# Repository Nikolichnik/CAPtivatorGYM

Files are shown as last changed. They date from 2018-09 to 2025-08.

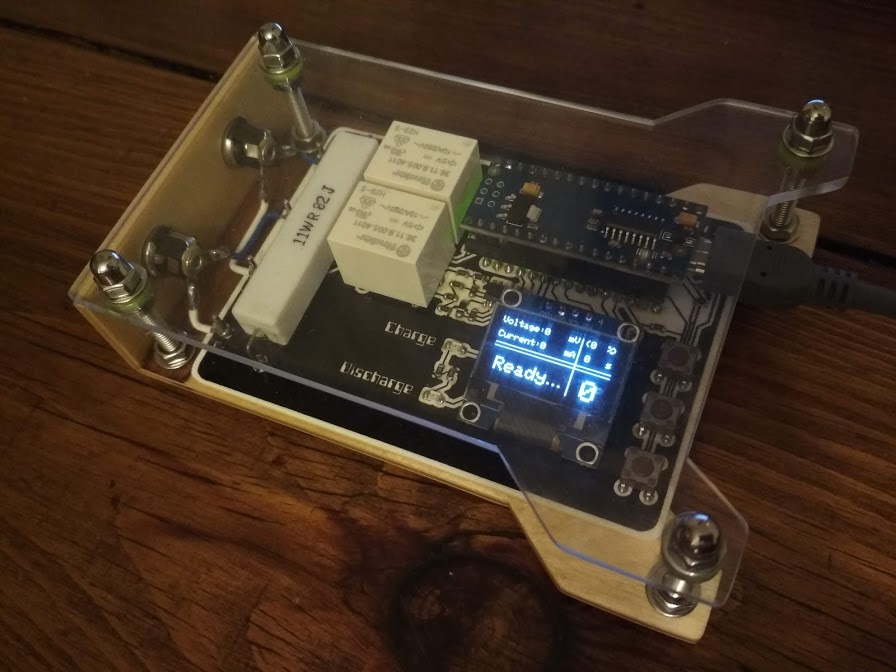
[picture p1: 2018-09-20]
CAPtivatorGYM.jpg

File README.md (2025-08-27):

# CAPtivatorGYM

<h4>Supercapacitor testing device.</h4> 

It is designed to automate process of charging/discharging supercapacitors while capturing, displaying and transmitting all relevant data both locally and through USB connection. Capable of independent operation as well as in conjuction with companion desktop software - <a href="https://github.com/Nikolichnik/CAPtivatorINTEL"><em>CAPtivatorINTEL</em></a>.

<hr>

<p align="center">
  
</p>

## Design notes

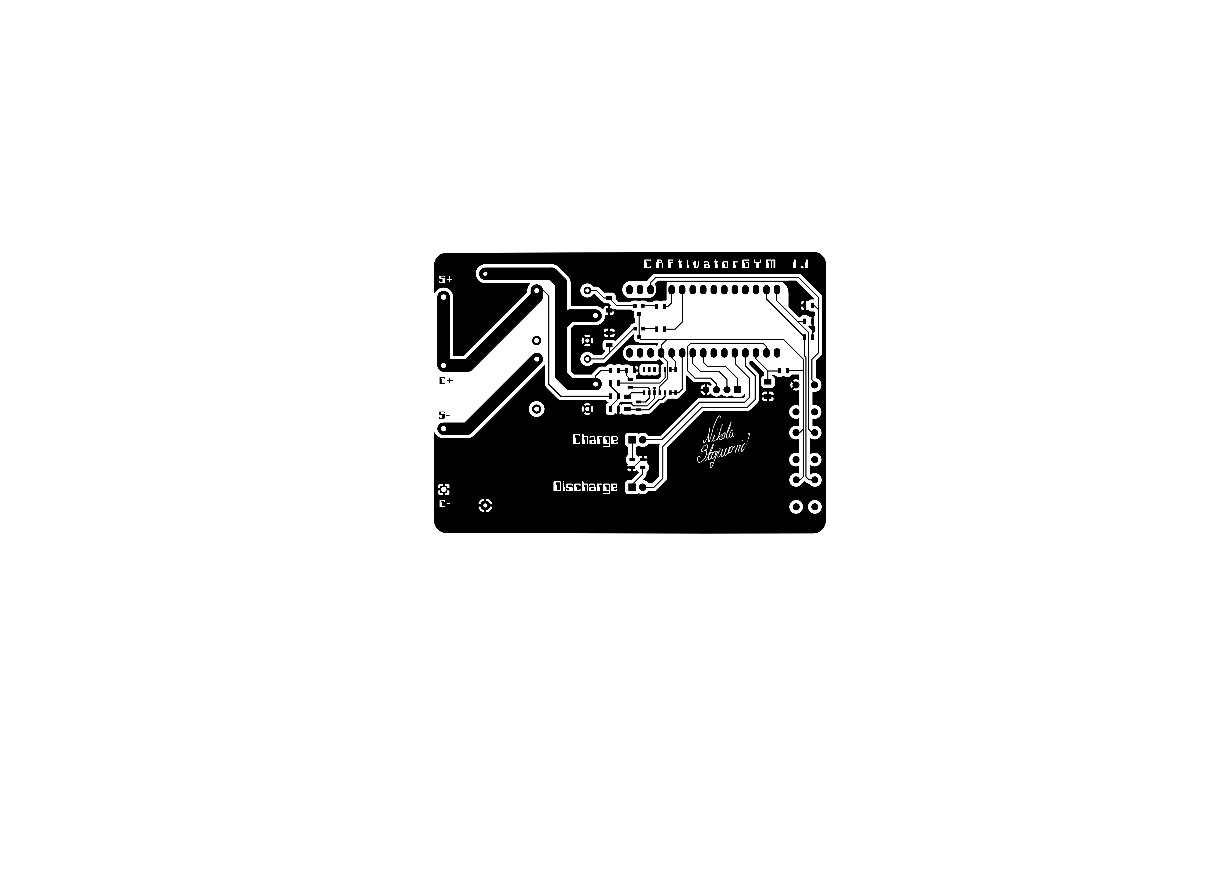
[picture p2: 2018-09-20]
pcb_KiCAD/CAP_gym-F.Cu.png

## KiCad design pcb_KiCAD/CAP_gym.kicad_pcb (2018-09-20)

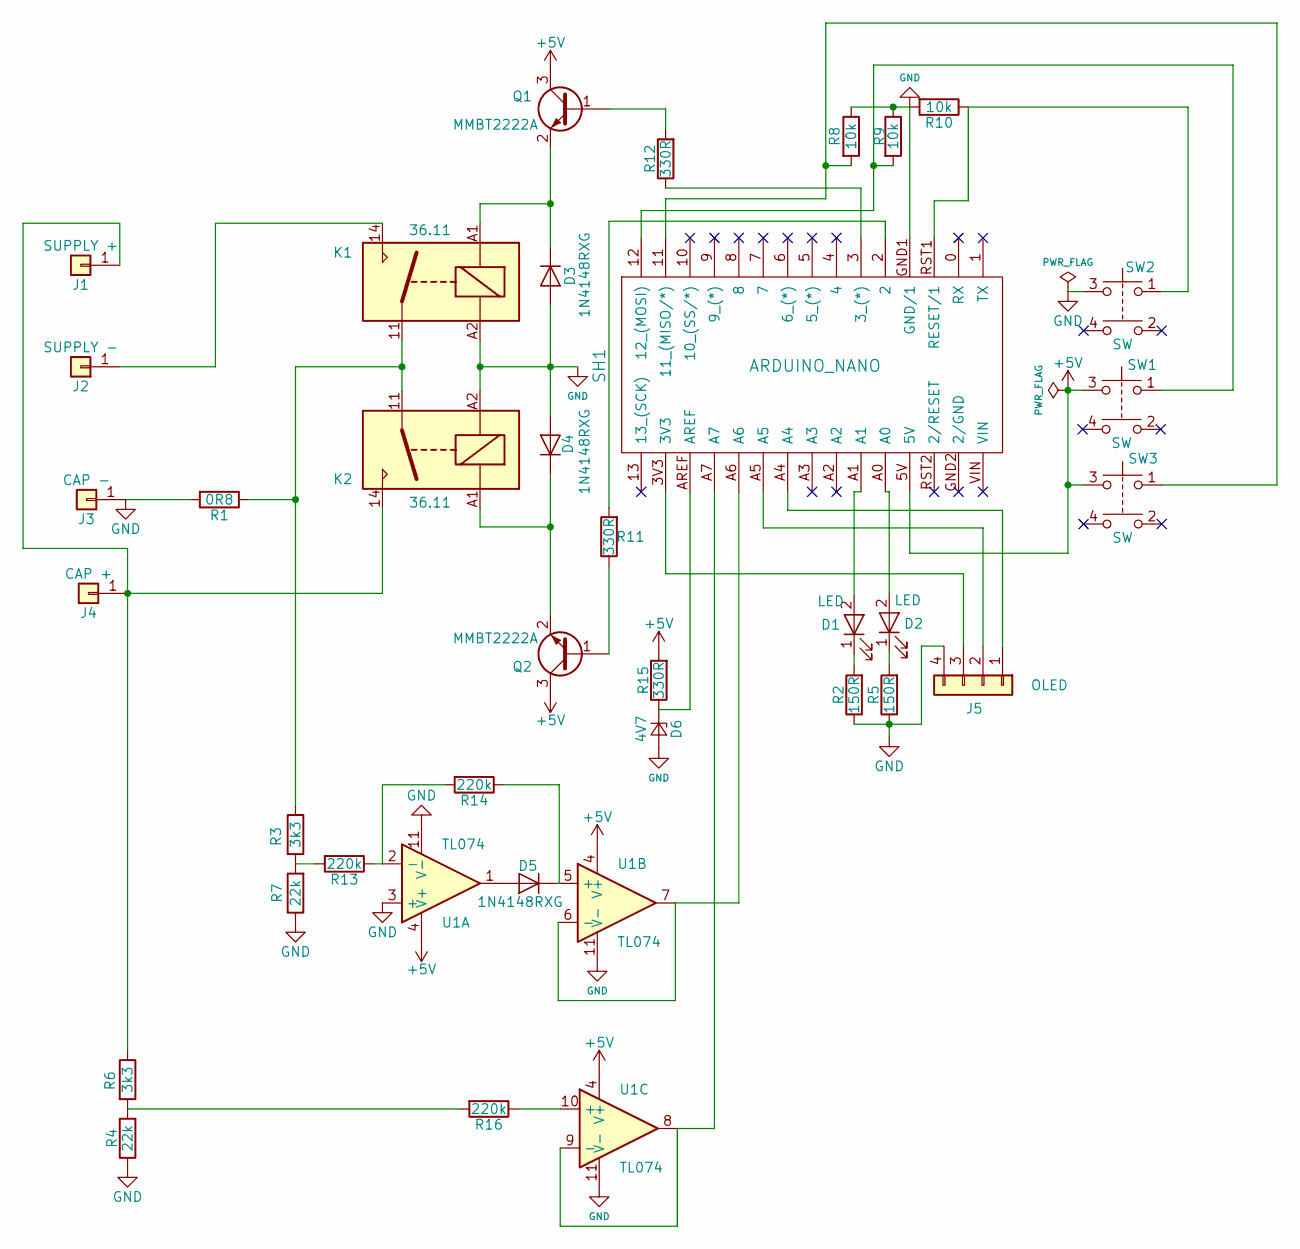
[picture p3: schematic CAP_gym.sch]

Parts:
D1, D2: LED; LED_D3.0mm
D3, D4, D5: 1N4148RXG; D_1206
D6: 4V7; D_MiniMELF
J1: SUPPLY +; Pin_Header_Straight_1x01_Pitch2.54mm
J2: SUPPLY -; Pin_Header_Straight_1x01_Pitch2.54mm
J3: CAP -; Pin_Header_Straight_1x01_Pitch2.54mm
J4: CAP +; Pin_Header_Straight_1x01_Pitch2.54mm
J5: OLED; Pin_Header_Straight_1x04_Pitch2.54mm
K1, K2: 36.11; Relay_SPDT_Finder_36.11
Q1, Q2: MMBT2222A; SOT-23
R1: 0R8; R_Axial_Power_L50.0mm_W9.0mm_P55.88mm
R2, R5: 150R; R_0805
R3, R6: 3k3; R_0805
R4, R7: 22k; R_0805
R8, R9, R10: 10k; R_0805
R11, R12, R15: 330R; R_0805
R13, R14, R16: 220k; R_0805
SH1: ARDUINO_NANO; ARDUINO_NANO_2_CONTOUR_ELL
SW1, SW2, SW3: SW; SW_TH_Tactile_Omron_B3F-10xx
U1: TL074; SO14

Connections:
+5V: Q1.3 (C), Q2.3 (C), R15.2, SH1.5V, SW1.3, SW3.3, U1.4 (V+)
GND: D3.2 (A), D4.2 (A), D6.2 (A), J3.1, J5.4, K1.A2, K2.A2, R1.2, R2.1, R4.1, R5.1, R7.1, R8.1, R9.1, R10.2, SH1.GND1 (GND/1), SW2.3, U1.3 (+), U1.11 (V-)
unnamed: D1.1 (K), R2.2
unnamed: D1.2 (A), SH1.A1
unnamed: D2.1 (K), R5.2
unnamed: D2.2 (A), SH1.A0
unnamed: D3.1 (K), K1.A1, Q1.2 (E)
unnamed: D4.1 (K), K2.A1, Q2.2 (E)
unnamed: D5.1 (K), R14.1, U1.5 (+)
unnamed: D5.2 (A), U1.1
unnamed: D6.1 (K), R15.1, SH1.AREF
unnamed: J1.1, J4.1, K2.14, R6.1
unnamed: J2.1, K1.14
unnamed: J5.1, SH1.A4
unnamed: J5.2, SH1.A5
unnamed: J5.3, SH1.3V3
unnamed: K1.11, K2.11, R1.1, R3.1
unnamed: Q1.1 (B), R12.2
unnamed: Q2.1 (B), R11.1
unnamed: R8.2, SH1.11 (11_(MISO/*)), SW3.1
unnamed: R9.2, SH1.12 (12_(MOSI)), SW1.1
unnamed: R10.1, SH1.RST1 (RESET/1), SW2.1
unnamed: R11.2, SH1.2
unnamed: R12.1, SH1.3 (3_(*))
unnamed: R13.1, R14.2, U1.2 (-)
unnamed: R3.2, R7.2, R13.2
unnamed: R16.1, U1.10 (+)
unnamed: R4.2, R6.2, R16.2
unnamed: SH1.A6, U1.6 (-), U1.7
unnamed: SH1.A7, U1.8, U1.9 (-)

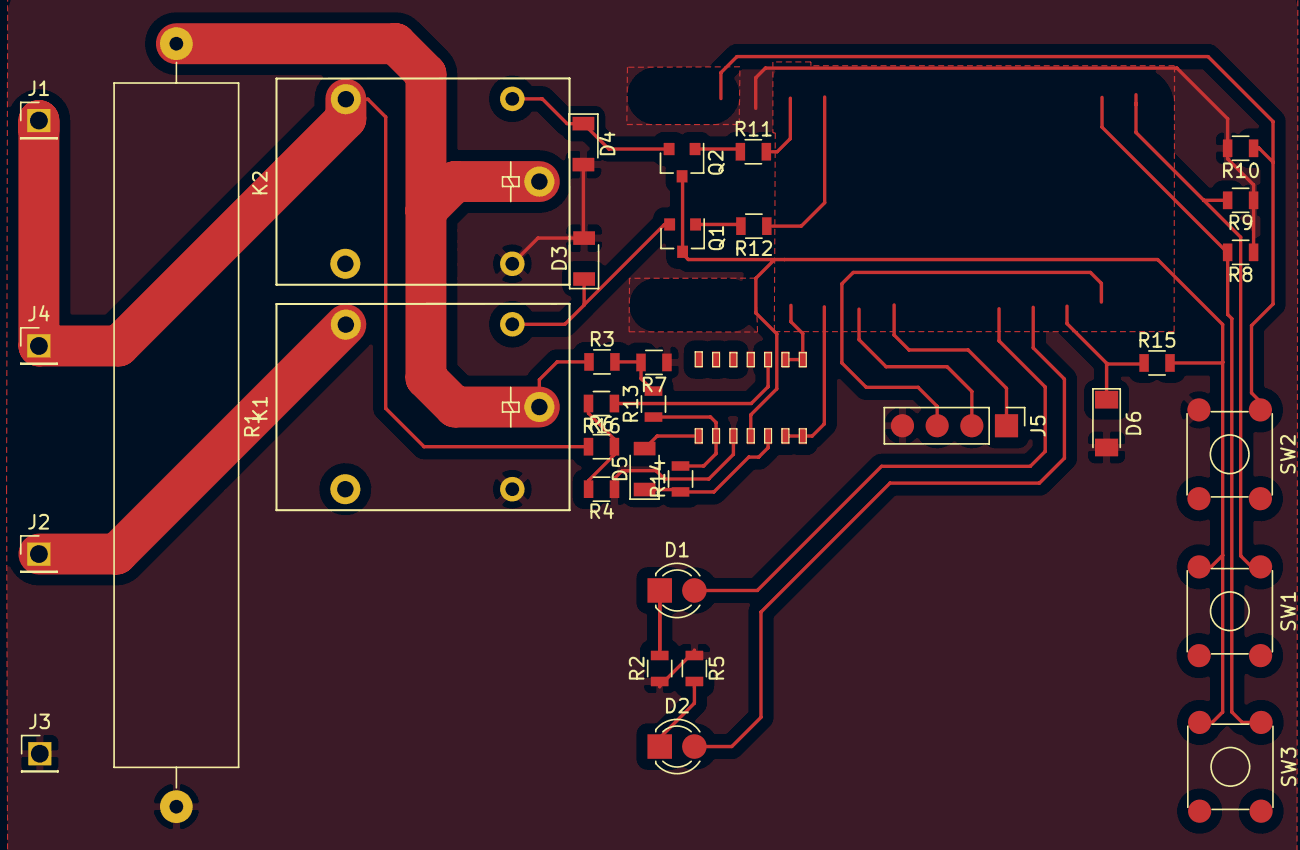
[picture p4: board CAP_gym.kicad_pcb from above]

Board: 2 copper layers, 36 parts (1 on the bottom side), 30 nets.

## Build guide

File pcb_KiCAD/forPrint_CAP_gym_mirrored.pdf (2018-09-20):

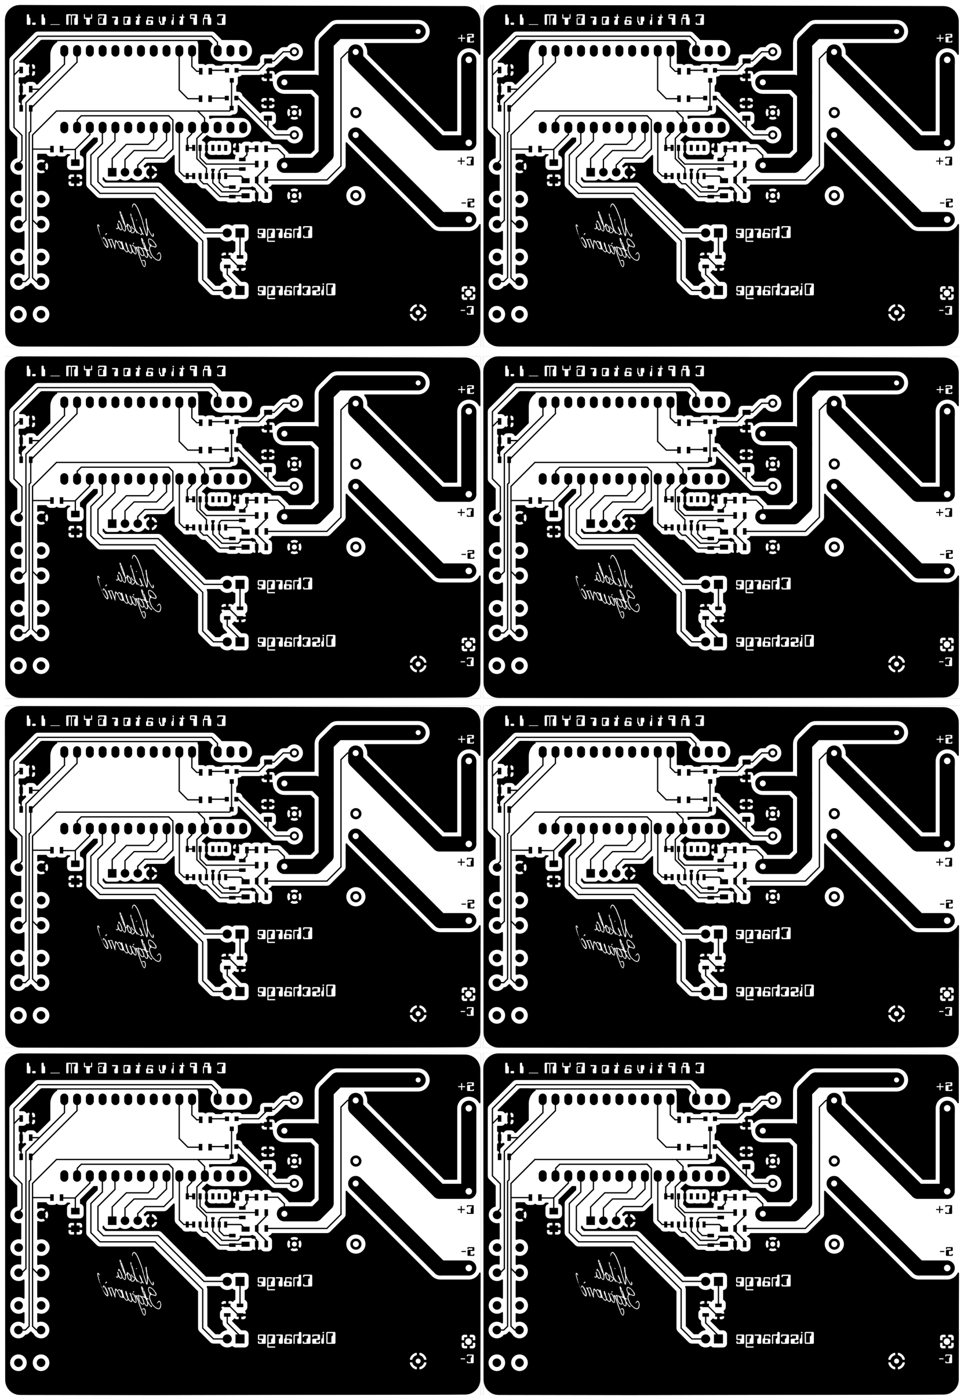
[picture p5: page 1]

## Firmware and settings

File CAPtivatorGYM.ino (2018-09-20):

#include <Wire.h>
#include <Adafruit_SSD1306.h>
#include <Adafruit_GFX.h>
#include "Pitches.h"

// bpSPD Button -----------------------------------------------------------------------------------
#define bpSPD 12

// OLED display TWI address -----------------------------------------------------------------------
#define OLED_ADDR   0x3C

// Reset pin not used on 4-pin OLED module --------------------------------------------------------
Adafruit_SSD1306 display(-1);  // -1 = no reset pin

// 128 x 32 pixel display -------------------------------------------------------------------------
#if (SSD1306_LCDHEIGHT != 64)
#error("Height incorrect, please fix Adafruit_SSD1306.h!");
#endif

// Voltage measurement ----------------------------------------------------------------------------
#define NUM_SAMPLES 10
#define REF_VOLTAGE 4.175

float R = 0.82;               // Initialisation of variables for resistance, and for maximum and
float Vmax = 2.70;            // minimum voltage
float Vmin = 0.10;
float I = 0.00;               // Initialisation of variable for current
float V = 0.00;               // Initialisation of variable for voltage on capacitors
float Vr = 0.00;              // Initialisation of variable for voltage on discharge resistor
float Vperc = 0;              // Declaration of variable percentage of Vmax
float C = 0;                  // Declaration of variable for capacitance
float t = 0;                  // Initialisation of variable for time

byte cycle = 0;               // Initialise counter for current cycle, number of cycles
byte cycles = 3;
byte cyclesMax = 9;           // Initialisation of variable determining maximum number of cycles

// Relays ---------------------------------------------------------------------------------------
byte relayCS = 3;              // Define pin connected to charging relay (CS == "Capacitor - Supply")
byte relayCD = 2;              // Define pin connected to discharging relay (CD == "Capacitor - Discharge")
// Button bpT -----------------------------------------------------------------------------------
int bpTPin = 11;              // The number of the input pin for screen toggle
boolean bpTState = HIGH;      // The current state of the output pin
int bpTReading;               // The current reading from the input pin
boolean bpTPrevious = LOW;    // The previous reading from the input pin
long bpTTime = 0;             // The last time the output pin was toggled
long bpTDebounce = 100;       // The debounce time, increase if the output flickers
int bpTVar = 0;               // Variable recording state of screen Toggle button
// Button bpSPD ---------------------------------------------------------------------------------
int bpSPDVar = 1;             // Variable recording state of screen bpSPD button
// Button timing variables
int debounce = 20;            // ms debounce period to prevent flickering when pressing or releasing the button
int DCgap = 250;              // max ms between clicks for a double click event
int holdTime = 1000;          // ms hold period: how long to wait for press+hold event
int longHoldTime = 3000;      // ms long hold period: how long to wait for press+hold event
// Other button variables
boolean buttonVal = HIGH;     // value read from button
boolean buttonLast = HIGH;    // buffered value of the button's previous state
boolean DCwaiting = false;    // whether we're waiting for a double click (down)
boolean DConUp = false;       // whether to register a double click on next release, or whether to wait and click
boolean singleOK = true;      // whether it's OK to do a single click
long downTime = -1;           // time the button was pressed down
long upTime = -1;             // time the button was released
boolean ignoreUp = false;     // whether to ignore the button release because the click+hold was triggered
boolean waitForUp = false;          // when held, whether to wait for the up event
boolean holdEventPast = false;      // whether or not the hold event happened already
boolean longHoldEventPast = false;  // whether or not the long hold event happened already
// Caps -----------------------------------------------------------------------------------------
byte capVoltage = A7;
byte capCurrent = A6;
// LEDs -----------------------------------------------------------------------------------------
byte LEDCharge = A1;
byte LEDDischarge = A0;
// Graph vars -------------------------------------------------------------------------------------
double x, y;
double ox, oy ;
// Koef -------------------------------------------------------------------------------------------
double koef = 1.1376;
// Speaker ----------------------------------------------------------------------------------------
byte speaker = 10;

//-------------------------------------------------------------------------------------------------
//                                          SETUP/LOOP
//-------------------------------------------------------------------------------------------------


void setup() {
  analogReference(EXTERNAL);
  Serial.begin(9600);
  display.begin(SSD1306_SWITCHCAPVCC, OLED_ADDR);
  display.display();
  delay(2000);
  display.clearDisplay();  
  
  // Relays ------------------------------------------------------------------------------------
  pinMode(relayCS, OUTPUT);
  digitalWrite(relayCS, LOW);
  pinMode(relayCD, OUTPUT);
  digitalWrite(relayCD, LOW);
  // Button bpT---------------------------------------------------------------------------------
  pinMode(bpTPin, INPUT);
  // Button bpSPD-------------------------------------------------------------------------------
  pinMode(bpSPD, INPUT);
  // LEDs---------------------------------------------------------------------------------------
  pinMode(LEDCharge, OUTPUT);
  digitalWrite(LEDCharge, LOW);
  pinMode(LEDDischarge, OUTPUT);
  digitalWrite(LEDDischarge, LOW);

  testdrawline();
  display.display();
  display.clearDisplay();

  playMelody(1);
}

void loop() {
  
  checkSPD();
  
  switch (bpSPDVar) {
    case 1:
      cycle = 0;
      idle();      
      break;
    case 2:
      advanceCyclesNumber();
      break;
    case 3:    
    if (cycle < cycles) {
        cycle++;
        discharge();
        charge();
      } else {
        discharge();
        playMelody(3);
        bpSPDVar = 1;
        cycle = 0;
        Serial.println("Measurement complete!");     
      }
      break;
  }
}

//-------------------------------------------------------------------------------------------------
//                                        FUNCTIONS
//-------------------------------------------------------------------------------------------------

void discharge() {                      // Function for discharging   
  unsigned long startTime = millis();         // Start measuring time in milliseconds
  unsigned long currentTime = 0;              // Mark down time in milliseconds again
  unsigned long tPause = 0;
  Serial.println("Discharging...");  
  V = measureVoltage();
  display.clearDisplay();                      // Calculate percentage that current voltage is to value Vmax
  while (V > Vmin) {                           // While measured voltage is lower than Vmax...
    checkSPD();                                // Check state of SPD button
      currentTime = millis();
      if (bpSPDVar == 1) {
        digitalWrite(relayCD, LOW);            // Disconnect capacitors discharging resistor
        digitalWrite(relayCS, LOW);            // Connect capacitors to supply
        digitalWrite(LEDDischarge, LOW);
        tPause = t - (currentTime - startTime);
      } else if (bpSPDVar == 2) { 
        advanceCyclesNumber();
      } else if (bpSPDVar == 4) {
        bpSPDVar = 1; 
        break;
      } else {
        digitalWrite(LEDDischarge, HIGH);       // Turn on charge LED
        digitalWrite(relayCS, LOW);             // Disconnect capacitors discharging resistor
        digitalWrite(relayCD, HIGH);            // Connect capacitors to supply
        V = measureVoltage();
        Vperc = (V / Vmax) * 100;
        I = measureCurrent();                   // Read voltage on discharge resistor, taking voltage divider into consideration
                                                // Calculate capacitor discharge current (converted to mA)        
        t = currentTime - startTime + tPause;   // Calculate time passed between two marks
        if (V > ((0.368 * Vmax)+0.002)) {       // While voltage is less than 63.2% of Vmin,
          C = -1;                               // set C to -1 (see displayOut())
        } else if (V > ((0.368 * Vmax)-0.002) && V < ((0.368 * Vmax)+0.002)) {         // When voltage reaches 63.2% of Vmax,
          C = (t / 1000) / R;                   // calculate capacitance (while converting time from ms to s)
        }
        displayOut();                           // Keep updating display
        Serial.print((int)(V * 1000));          // Send values for V (converted to mV), I (in mA), C (in F) and t (converted to s) over Serial
        Serial.print(",");
        Serial.print((int)I);
        Serial.print(",");        
        Serial.println((int)(t / 1000));
        delay(3);
      }
  }  
  digitalWrite(relayCD, LOW);                   // Disconnect capacitors from supply
  digitalWrite(LEDDischarge, LOW);              // Turn off charge LED
  t = 0;                                        // Reset time to 0
  Serial.print("Discharge cycle ");
  Serial.print(cycle);
  Serial.print(" done! C = ");
  Serial.println(C);
  playMelody(2);
  //delay(3000); 
}

void charge() {                         // Function for charging  
  unsigned long startTime = millis();         // Start measuring time in milliseconds
  unsigned long currentTime = 0;              // Mark down time in milliseconds again
  unsigned long tPause = 0;
  Serial.println("Charging...");
  V = measureVoltage();
  display.clearDisplay();                     // Calculate percentage that current voltage is to value Vmax
  while (V < Vmax) {                          // While measured voltage is lower than Vmax...
    checkSPD();                               // Check state of SPD button
      currentTime = millis();
      if (bpSPDVar == 1) {
        digitalWrite(relayCD, LOW);           // Disconnect capacitors discharging resistor
        digitalWrite(relayCS, LOW);           // Connect capacitors to supply
        digitalWrite(LEDCharge, LOW);
        tPause = t - (currentTime - startTime);
      } else if (bpSPDVar == 2) { 
        advanceCyclesNumber();
      } else if (bpSPDVar == 4) {
        bpSPDVar = 1; 
        break;
      } else {
        digitalWrite(LEDCharge, HIGH);          // Turn on charge LED
        digitalWrite(relayCD, LOW);             // Disconnect capacitors discharging resistor
        digitalWrite(relayCS, HIGH);            // Connect capacitors to supply
        V = measureVoltage();
        Vperc = (V / Vmax) * 100;
        I = measureCurrent();                   // Read voltage on discharge resistor, taking voltage divider into consideration
                                                // Calculate capacitor discharge current (converted to mA)        
        t = currentTime - startTime + tPause;   // Calculate time passed between two marks
        if (V < ((0.632 * Vmax)-0.002)) {       // While voltage is less than 63.2% of Vmin,
          C = -1;                               // set C to -1 (see displayOut())
        } else if (V > ((0.632 * Vmax)-0.002) && V < ((0.632 * Vmax)+0.002)) {         // When voltage reaches 63.2% of Vmax,
          C = (t / 1000) / R;                   // calculate capacitance (while converting time from ms to s)
        }
        displayOut();                           // Keep updating display
        Serial.print((int)(V * 1000));          // Send values for V (converted to mV), I (in mA), C (in F) and t (converted to s) over Serial
        Serial.print(",");
        Serial.print((int)I);
        Serial.print(",");        
        Serial.println((int)(t / 1000));
        delay(3);
      }
  }  
  digitalWrite(relayCS, LOW);         // Disconnect capacitors from supply
  digitalWrite(LEDCharge, LOW);       // Turn off charge LED
  t = 0;                              // Reset time to 0
  Serial.print("Charge cycle ");
  Serial.print(cycle);
  Serial.print(" done! C = ");
  Serial.println(C);
  playMelody(2);
  //delay(3000);
}

void idle() {                           // Function for idling
  digitalWrite(relayCS, LOW);           // Disconnect capacitors from supply
  digitalWrite(relayCD, LOW);           // Disconnect capacitors from discharge resistor
  //Serial.println("Ready...");
  V = measureVoltage();
  Vperc = (V / Vmax) * 100;             // Calculate percentage that current voltage is to value Vmax
  I = measureCurrent();
  displayOut();
}

void displayOut() {                       // Function for display handling
  bpTCheck();                             // This way user can switch between readout and graph mid-measurement. Graph would be partial, however.
  if (bpTVar == 0) {
    display.clearDisplay();
    display.setTextColor(WHITE);
    display.setTextSize(1);
    display.setCursor(0, 0);
    display.print("Voltage: ");
    display.setCursor(48, 0);
    display.print((int)(V * 1000));            // Voltage converted to mV
    display.setCursor(75, 0);
    display.print("mV");
    display.setCursor(93, 0);
    display.print("(");
    display.setCursor(99, 0);
    display.print((int)Vperc);
    display.setCursor(117, 0);
    display.print("%");
    display.setCursor(121, 0);
    display.print(")");
    display.setCursor(0, 16);
    display.print("Current: ");
    display.setCursor(48, 16);
    display.print((int)I);
    display.setCursor(75, 16);
    display.print("mA");
    display.setCursor(97, 16);
    display.print((int)(t / 1000));            // Time converted from ms to s
    display.setCursor(120, 16);
    display.print("s");
    display.drawFastHLine(0, 29, 128, WHITE);
    display.drawFastHLine(0, 33, 128, WHITE);
    display.drawFastVLine(89, 0, 64, WHITE);
    display.setCursor(6, 45);
    if (bpSPDVar == 1) {
      display.setTextSize(2);
      display.print("Ready");
      display.setCursor(65, 51);
      display.setTextSize(1);
      display.print("...");
    } else if (bpSPDVar == 2) {
      display.setCursor(4, 45);
      display.setTextSize(2);
      display.print("#CyS:");
      display.setTextSize(3);
      display.setCursor(65, 42);
      display.print(cycles);
    } else {
      display.setTextSize(3);
      if (C == -1) {
        display.setCursor(6, 35);
        display.print("...");
      } else {
        display.setCursor(6, 42);
        display.print((int)C);
      }
      display.setCursor(69, 42);
      display.print("F");
    }
    display.setTextSize(3);
    display.setCursor(103, 42);
    display.print(cycle);
    display.display();
    display.clearDisplay();
  } else {
    DrawCGraph(display, t / 1000, V, 9, 60, 100, 57, 0, 1500, 50, 0, 3, 1, 0, "", true);
    DrawBarChartV(display, I / 1000, 113,  61, 5, 57, 0, 3 , 1, 0, "", true);
  }
}

void DrawCGraph(Adafruit_SSD1306 &d, double x, double y, double gx, double gy, double w, double h, double xlo, double xhi, double xinc, double ylo, double yhi, double yinc, double dig, String title, boolean Redraw) {

  /*

    function to draw a cartesian coordinate system and plot whatever data you want
    just pass x and y and the graph will be drawn huge arguement list

    &display to pass the display object, mainly used if multiple displays are connected to the MCU
    x = x data point
    y = y datapont
    gx = x graph location (lower left)
    gy = y graph location (lower left)
    w = width of graph
    h = height of graph
    xlo = lower bound of x axis
    xhi = upper bound of x asis
    xinc = division of x axis (distance not count)
    ylo = lower bound of y axis
    yhi = upper bound of y asis
    yinc = division of y axis (distance not count)
    title = title of graph
    &redraw = flag to redraw graph on fist call only

  */

  double i;
  double temp;
  int rot, newrot;

  if (Redraw == true) {
    /*Redraw = false;
      d.fillRect(0, 0,  127 , 16, WHITE);
      d.setTextColor(BLACK, WHITE);
      d.setTextSize(1);
      d.setCursor(2, 4);
      d.println(title);*/
    ox = (x - xlo) * ( w) / (xhi - xlo) + gx;
    oy = (y - ylo) * (gy - h - gy) / (yhi - ylo) + gy;
    // draw y scale
    d.setTextSize(1);
    d.setTextColor(WHITE, BLACK);
    for ( i = ylo; i <= yhi; i += yinc) {
      // compute the transform
      // note my transform funcition is the same as the map function, except the map uses long and we need doubles
      temp =  (i - ylo) * (gy - h - gy) / (yhi - ylo) + gy;
      if (i == 0) {
        d.drawFastHLine(gx - 2, temp, w + 2, WHITE);
      }
      else {
        d.drawFastHLine(gx - 2, temp, 2, WHITE);
      }
      d.setCursor(gx - 9, temp - 3);
      d.println(i, dig);
    }
    // draw x scale
    for (i = xlo; i <= xhi; i += xinc) {
      // compute the transform
      d.setTextSize(1);
      d.setTextColor(WHITE, BLACK);
      temp =  (i - xlo) * ( w) / (xhi - xlo) + gx;
      if (i == 0) {
        d.drawFastVLine(temp, gy - h, h + 2, WHITE);
      }
      else {
        d.drawFastVLine(temp, gy, 2, WHITE);
      }
      d.setCursor(temp, gy + 6);
      d.println(i, dig);
    }
  }

  // graph drawn now plot the data
  // the entire plotting code are these few lines...

  x =  (x - xlo) * ( w) / (xhi - xlo) + gx;
  y =  (y - ylo) * (gy - h - gy) / (yhi - ylo) + gy;
  d.drawLine(ox, oy, x, y, WHITE);
  d.drawLine(ox, oy - 1, x, y - 1, WHITE);
  ox = x;
  oy = y;

  // up until now print sends data to a video buffer NOT the screen
  // this call sends the data to the screen
  d.display();
}

void DrawBarChartV(Adafruit_SSD1306 &d, double curval, double x , double y , double w, double h , double loval , double hival , double inc , double dig, String label, bool Redraw) {

  /*
    This method will draw a vertical bar graph for single input
    it has a rather large arguement list and is as follows

    &d to pass the display object, mainly used if multiple displays are connected to the MCU
    curval = date to graph (must be between loval and hival)
    x = position of bar graph (lower left of bar)
    y = position of bar (lower left of bar)
    w = width of bar graph
    h =  height of bar graph (does not need to be the same as the max scale)
    loval = lower value of the scale (can be negative)
    hival = upper value of the scale
    inc = scale division between loval and hival
    dig = format control to set number of digits to display. (not includeing the decimal)
    label = bottom lable text for the graph
    redraw = flag to redraw display. only on first pass (to reduce flickering)

  */

  double stepval, my, level, i, data;

  if (Redraw) {
    /*Redraw = false;
      d.fillRect(0, 0,  127 , 14, WHITE);
      d.setTextColor(BLACK, WHITE);
      d.setTextSize(1);
      d.setCursor(2, 4);
      d.println(label);*/
    // step val basically scales the hival and low val to the height
    // deducting a small value to eliminate round off errors
    // this val may need to be adjusted
    stepval = ( inc) * (double (h) / (double (hival - loval))) - .001;
    for (i = 0; i <= h; i += stepval) {
      my =  y - h + i;
      d.drawFastHLine(x + w + 0, my, 2, WHITE);
      // draw lables
      d.setTextSize(1);
      d.setTextColor(WHITE, BLACK);
      d.setCursor(x + w + 4, my - 3 );
      data = hival - ( i * (inc / stepval));
      d.print(data, dig);
    }
  }
  // compute level of bar graph that is scaled to the  height and the hi and low vals
  // this is needed to accompdate for +/- range
  level = (h * (((curval - loval) / (hival - loval))));
  // draw the bar graph
  // write a upper and lower bar to minimize flicker cause by blanking out bar and redraw on update
  d.drawRect(x, y - h, w, h, WHITE);
  d.fillRect(x, y - h, w, h - level,  BLACK);
  d.drawRect(x, y - h, w, h, WHITE);
  d.fillRect(x, y - level, w,  level, WHITE);
  // up until now print sends data to a video buffer NOT the screen
  // this call sends the data to the screen
  d.display();
}

void advanceCyclesNumber() {            // Function for advancing number of cycles
  if (cycles < cyclesMax) {
    cycles++;
  } else {
    cycles = 1;
  }
  Serial.println(cycles);
  displayOut();
  delay(1000);
  bpSPDVar = 1;
}

boolean bpTCheck() {                    // Function for checking state of toggle button
  bpTReading = digitalRead(bpTPin);
  if (bpTReading == HIGH && bpTPrevious == LOW && millis() - bpTTime > bpTDebounce) {
    if (bpTState == HIGH) {
      bpTState = LOW;
      bpTVar = 0;
    } else {
      bpTState = HIGH;
      bpTTime = millis();
      bpTVar = 1;
    }
  }
  bpTPrevious = bpTReading;
  return bpTState;
}

void testdrawline() {
  display.clearDisplay();
  for (int16_t i = 0; i < display.height(); i += 4) {
    display.drawLine(display.width() - 1, 0, 0, i, WHITE);
    display.display();
    delay(1);
  }
  for (int16_t i = 0; i < display.width(); i += 4) {
    display.drawLine(display.width() - 1, 0, i, display.height() - 1, WHITE);
    display.display();
    delay(1);
  }
}
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

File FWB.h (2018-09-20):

// for types of button presses for the Arduino: click, double-click, long press (and release), very long press 
// might work with other controllers. modified from: http://pastebin.com/gQLTrHVF
/*
  i had to make a few changes (update it?) to make the code work. main changes:
  1. REMOVED: #include "WProgram.h" (no longer required).
  2. CHANGED: bpUP TO bp.
  3. ADDED: event listeners for ALL four types of presses in the sample code.
  4. CHANGED: time intervals for single, double, long clicks and for long press. these feel more intuitive to me.
  5. CHANGED: event OnLongPress is raised ONLY after the button is released. this, again, feels more intuitive. code is tested and at http://pastebin.com/87cCn6h9
*/

//
// jb_exe
// Class from the code of JEFF'S ARDUINO BLOG
// http://jmsarduino.blogspot.com/2009/10/4-way-button-click-double-click-hold.html
// 
// the modified version at http://pastebin.com/gQLTrHVF
// further modified by mahesh [at] tinymogul.com
//
// Further edited by Nikolichnik (nikola7sto@gmail.com)
//

// How to use me :
// "FWB_Project.pde"
// #include "FWB.h"
// #define BP 0 //the pin where your button is connected
//
// FWB bp;
//
// void OnClick(int pin) {
//   //Your code here
// }
//
// void OnDblClick(int pin) {
//   //Your code here
// }
//
// void OnLongPress(int pin) {
//   //Your code here
// }
//
// void OnVLongPress(int pin) {
//   //Your code here
// }
//
// void setup()
// {
//   // errors in code fixed here. Empty event handlers added.
//   bp.Configure(BP);
//   bp.OnClick = OnClick;
//   bp.OnDblClick = OnDblClick;
//   bp.OnLongPress = OnLongPress;
//   bp.OnVLongPress = OnVLongPress;
// }
//
// void loop()
// {
//  // Test button state
//  bp.CheckBP();
// }

#define PULL_UP 1
#define PULL_DOWN 0

class FWB
{
	
private:

  int _pin;
  boolean _pullMode;

  // Properties //
  
  int Debounce;                         // Debounce period to prevent flickering when pressing or releasing the button (in ms)
  int DblClickDelay;					// Max period between clicks for a double click event (in ms)
  int LongPressDelay;					// Hold period for a long press event (in ms)
  int VLongPressDelay;					// Hold period for a very long press event (in ms)
    
  // Variables //
  
  boolean _state;						// Value read from button
  boolean _lastState;					// Last value of button state
  boolean _dblClickWaiting;				// whether we're waiting for a double click (down)
  boolean _dblClickOnNextUp;			// whether to register a double click on next release, or whether to wait and click
  boolean _singleClickOK;				// whether it's OK to do a single click

  long _downTime;						// time the button was pressed down
  long _upTime;							// time the button was released

  boolean _ignoreUP;					// whether to ignore the button release because the click+hold was triggered
  boolean _waitForUP;					// when held, whether to wait for the up event
  boolean _longPressHappened;			// whether or not the hold event happened already
  boolean _vLongPressHappened;			// whether or not the long hold event happened already

public:

  void (*OnClick)(int pin);
  void (*OnDblClick)(int pin);
  void (*OnLongPress)(int pin);
  void (*OnVLongPress)(int pin);

  FWB()
  {
    // Initialization of properties
	
    Debounce = 20;
    DblClickDelay = 250;
    LongPressDelay = 3000;
 // LongPressDelay = 1000;
    VLongPressDelay = 5000;
 // VLongPressDelay = 3000;

    // Initialization of variables
	
    _state = true;
    _lastState = true;
    _dblClickWaiting = false;
    _dblClickOnNextUp = false;
    _singleClickOK = false; //Default = true
    _downTime = -1;
    _upTime = -1;
    _ignoreUP = false;
    _waitForUP = false;
    _longPressHappened = false;
    _vLongPressHappened = false;
  }
  
  void Configure(int pin, int pullMode = PULL_DOWN)
  {
    _pin = pin;
    _pullMode = pullMode;
    pinMode(_pin, INPUT);
  }

  void CheckBP(void)
  {
    int resultEvent = 0;
    long millisRes = millis();
    _state = digitalRead(_pin) == HIGH;

    // Button pressed down
	
    if (_state != _pullMode && _lastState == _pullMode && (millisRes - _upTime) > Debounce)
    {
    //Serial.println("button down");
      _downTime = millisRes;
      _ignoreUP = false;
      _waitForUP = false;
      _singleClickOK = true;
      _longPressHappened = false;
      _vLongPressHappened = false;
	  
      if ((millisRes - _upTime) < DblClickDelay && _dblClickOnNextUp == false && _dblClickWaiting == true)
        _dblClickOnNextUp = true;
      else
        _dblClickOnNextUp = false;
      _dblClickWaiting = false;
    }
	
    // Button released
	
    else if (_state == _pullMode && _lastState != _pullMode && (millisRes - _downTime) > Debounce)
    {
      //Serial.println("button up");
	  
      if (_ignoreUP == false) //Replace "(!_ignoreUP)" by "(not _ignoreUP)"
      {
        _upTime = millisRes;
		
        if (_dblClickOnNextUp == false) 
			_dblClickWaiting = true;
        else
        {
          resultEvent = 2;
          _dblClickOnNextUp = false;
          _dblClickWaiting = false;
          _singleClickOK = false;
        }
      }
    }

    // Test for normal click event: DblClickDelay expired
	
    if (_state == _pullMode && (millisRes - _upTime) >= DblClickDelay && _dblClickWaiting == true && _dblClickOnNextUp == false && _singleClickOK == true && resultEvent != 2)
    {
      resultEvent = 1;
      _dblClickWaiting = false;
    }

    // added code: raise OnLongPress event when only when the button is released
    if (_state == _pullMode && _longPressHappened && !_vLongPressHappened) {
      resultEvent = 3;
      _longPressHappened = false;
    }

    // Test for hold
	
    if (_state != _pullMode && (millisRes - _downTime) >= LongPressDelay)
    {
		
      // Trigger "normal" hold
	  
      if (_longPressHappened == false)
      {
        // resultEvent = 3;
        _waitForUP = true;
        _ignoreUP = true;
        _dblClickOnNextUp = false;
        _dblClickWaiting = false;
      //_downTime = millis();
        _longPressHappened = true;
      }
	  
      // Trigger "long" hold
	  
      if ((millisRes - _downTime) >= VLongPressDelay)
      {
        if (_vLongPressHappened == false)
        {
          resultEvent = 4;
          _vLongPressHappened = true;
        //_longPressHappened = false;
        }
      }
    }

    _lastState = _state;
    //if (resultEvent!=0)
    //  Serial.println((String)"resultEvent: " + (String) resultEvent);

    if (resultEvent == 1 && OnClick) OnClick(_pin);
    if (resultEvent == 2 && OnDblClick) OnDblClick(_pin);
    if (resultEvent == 3 && OnLongPress) OnLongPress(_pin);
    if (resultEvent == 4 && OnVLongPress) OnVLongPress(_pin);
    //  if (resultEvent != 0)
    //    Usb.println(resultEvent);
  }

};
